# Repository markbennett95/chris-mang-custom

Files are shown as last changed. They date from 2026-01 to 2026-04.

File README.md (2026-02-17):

# Custom Dual OD - Chris Mang

Custom dual drive in a 1590BB featuring a Zendrive on one side, and a modified bluesbreaker on the other.

## v1.0.0-build
1590BB encl. Works with `1590BB-2` of the [Dual Effect Order Switching Board](https://github.com/markbennett95/dual-effect-order-switching-board). Zendrive schematic is unchanged, using the "version" switch and a DG412. The Bluesbreaker is a pretty straight up clone with added clean blend.

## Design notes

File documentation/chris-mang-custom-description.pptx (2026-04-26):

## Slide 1

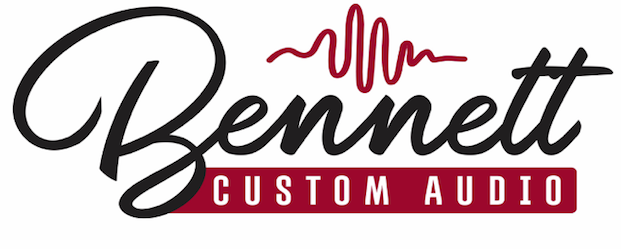
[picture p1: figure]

Custom Dual Overdrive

Introduction:
This custom-designed pedal features two independent overdrive circuits with order switching. The overdrives are modified versions of the Marshall BluesBreaker (“BB”), and the Zendrive by Hermida Audio (“Zendrive”). This pedal must be powered by a 9-18VDC, centre-negative power supply, capable of delivering 100mA of current – It does not have room for a battery inside. Like all our pedals, This pedal was designed and assembled by hand in St. John’s, NL.

Controls:
- BB VOL: Controls the output level of the BB. Turn it up for a louder signal.
- BB GAIN: Determines the amount of distortion in the BB. Turn it up for a more distorted, sustaining tone with more harmonics. Turn it down for a cleaner sound.
- BB CLEAN: A clean blend control that allows you to blend in some of the input signal in with the output signal of the overdrive. Counter-clockwise gives no clean signal, turning it up gives increasingly more clean signal in the output.
- BB PRESENCE: Enables fine-tuning of the overall brightness of the BB. We recommend turn it all the way counter-clockwise to start, then increase to taste if you find the tone to be too warm.
- BB TREBLE: Controls how warm or bright the BB output will be. Turn it down for a warmer tone, up for a brighter tone.
- ZEN VOL: Controls the output level of the Zendrive. Turn it up for a louder signal.
- ZEN GAIN: Determines the amount of distortion in the Zendrive. Turn it up for a more distorted, sustaining tone with more harmonics. Turn it down for a cleaner sound.
- ZEN TONE: Controls how warm or bright the tone will be. Turn it up for a bright sound.
- ZEN VERSION SWITCH: Sets the “version” of the Zendrive. Version I is brighter, with asymmetric clipping, less bass, and less overall gain. Version II has more gain, bass, and symmetric clipping for a warmer, fuzzier tone.
- ZEN VOICE: Sets the pre-gain bass of the Zendrive. Turning it down gives a warmer, less distorted sound. Turning it up gives a brighter sound with more overall gain.
- BB Footswitch: Toggles the BB on or off with true bypass. IF the LED next to it is illuminated, your signal is passing through the effect.
- Order Switch: Sets the order of the two overdrive circuits. UP puts the Zendrive before the BB in your signal chain, DOWN puts the BB before the Zendrive.
- ZEN Footswitch: Toggles the Zendrive on or off with true bypass. IF the LED next to it is illuminated, your signal is passing through the effect.

V1.0.0

www.bennettcustomaudio.ca
bennettcustomaudio@gmail.com

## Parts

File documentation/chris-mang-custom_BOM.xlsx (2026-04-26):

Value | Qty | Reference | Footprint
100nF | 3 | C14,C32,C33 | Capacitor_SMD:C_0805_2012Metric_Pad1.18x1.45mm_HandSolder
1uF | 1 | C11 | Capacitor_SMD:C_0805_2012Metric_Pad1.18x1.45mm_HandSolder
FerriteBead_Small | 3 | FB1,FB2,FB3 | Inductor_SMD:L_0805_2012Metric_Pad1.15x1.40mm_HandSolder
10k | 5 | R1,R17,R18,R42,R43 | Resistor_SMD:R_0805_2012Metric_Pad1.20x1.40mm_HandSolder
10M | 1 | R6 | Resistor_SMD:R_0805_2012Metric_Pad1.20x1.40mm_HandSolder
9V1 Zener | 1 | D1 | Diode_SMD:D_SOD-323_HandSoldering
Q_PMOS_GSD | 1 | Q1 | Package_TO_SOT_SMD:SOT-23_Handsoldering
BC848C | 2 | Q5,Q6 | Package_TO_SOT_SMD:SOT-23_Handsoldering
2N7002 | 3 | Q2,Q3,Q4 | Package_TO_SOT_SMD:SOT-23_Handsoldering
TLV9352 | 1 | U4 | Package_SO:SOIC-8_3.9x4.9mm_P1.27mm
NJM4580 | 1 | U3 | Package_SO:SOIC-8_3.9x4.9mm_P1.27mm
OPA1642 | 1 | U2 | Package_SO:SOIC-8_3.9x4.9mm_P1.27mm
DG412xY | 1 | U1 | Package_SO:SOIC-16_3.9x9.9mm_P1.27mm
1k | 3 | R8,R14,R29 | bca-footprints:R_L3.6mm_D1.6mm_P5.00mm_Horizontal
6.8k | 2 | R27,R30 | bca-footprints:R_L3.6mm_D1.6mm_P5.00mm_Horizontal
10k | 9 | R7,R10,R11,R13,R20,R26,R33,R40,R41 | bca-footprints:R_L3.6mm_D1.6mm_P5.00mm_Horizontal
18k | 1 | R12 | bca-footprints:R_L3.6mm_D1.6mm_P5.00mm_Horizontal
22k | 2 | R2,R3 | bca-footprints:R_L3.6mm_D1.6mm_P5.00mm_Horizontal
27k | 1 | R21 | bca-footprints:R_L3.6mm_D1.6mm_P5.00mm_Horizontal
33k | 1 | R22 | bca-footprints:R_L3.6mm_D1.6mm_P5.00mm_Horizontal
39k | 1 | R24 | bca-footprints:R_L3.6mm_D1.6mm_P5.00mm_Horizontal
100k | 6 | R15,R16,R31,R34,R35,R37 | bca-footprints:R_L3.6mm_D1.6mm_P5.00mm_Horizontal
150k | 1 | R25 | bca-footprints:R_L3.6mm_D1.6mm_P5.00mm_Horizontal
180k | 1 | R36 | bca-footprints:R_L3.6mm_D1.6mm_P5.00mm_Horizontal
220k | 1 | R28 | bca-footprints:R_L3.6mm_D1.6mm_P5.00mm_Horizontal
470k | 1 | R5 | bca-footprints:R_L3.6mm_D1.6mm_P5.00mm_Horizontal
680k | 1 | R9 | bca-footprints:R_L3.6mm_D1.6mm_P5.00mm_Horizontal
1M | 4 | R19,R23,R32,R39 | bca-footprints:R_L3.6mm_D1.6mm_P5.00mm_Horizontal
2.2M | 1 | R4 | bca-footprints:R_L3.6mm_D1.6mm_P5.00mm_Horizontal
1N4148 | 6 | D5,D6,D7,D8,D9,D10 | bca-footprints:Diode_DO-35_P5.00mm
1N5711 | 4 | D2,D3,D4,D11 | bca-footprints:Diode_DO-35_P5.00mm
47pF | 1 | C26 | bca-footprints:C_Ceramic_L4.0mm_W2.5mm_P2.50mm
100pF | 3 | C6,C18,C34 | bca-footprints:C_Ceramic_L4.0mm_W2.5mm_P2.50mm
470pF | 1 | C9 | bca-footprints:C_Ceramic_L4.0mm_W2.5mm_P2.50mm
3.3nF | 1 | C7 | bca-footprints:C_Film_L7.2mm_W2.5mm_P5.00mm
10nF | 6 | C15,C16,C17,C20,C21,C28 | bca-footprints:C_Film_L7.2mm_W2.5mm_P5.00mm
47nF | 1 | C25 | bca-footprints:C_Film_L7.2mm_W2.5mm_P5.00mm
0.1uF | 1 | C19 | bca-footprints:C_Film_L7.2mm_W2.5mm_P5.00mm
0.22uF | 3 | C4,C5,C8 | bca-footprints:C_Film_L7.2mm_W3.5mm_P5.00mm
0.47uF | 2 | C3,C10 | bca-footprints:C_Film_L7.2mm_W3.5mm_P5.00mm
1uF | 1 | C22 | bca-footprints:C_Film_L7.2mm_W5.00mm_P5.00mm
1uF | 1 | C23 | bca-footprints:CP_Radial_D4.0mm_P1.50mm
10uF | 3 | C24,C27,C29 | bca-footprints:CP_Radial_D4.0mm_P1.50mm
100uF | 6 | C1,C2,C12,C13,C30,C31 | bca-footprints:CP_Radial_D6.3mm_P2.50mm
SW_DIP_SPDT_2pos | 1 | SW2 | bca-footprints:DIP-8_W7.62mm_Socket
AudioJack_TRS | 2 | J2,J3 | bca-footprints:Rean_NYS215
Barrel_Jack_Switch | 1 | J1 | bca-footprints:DC_Jack_DC005
GNDSpring | 1 | G1 | bca-footprints:Keystone_628
10kC | 1 | RV1 | bca-footprints:R_POT
25kB | 1 | RV6 | bca-footprints:R_POT
50kB | 1 | RV3 | bca-footprints:R_POT
100kA | 3 | RV4,RV8,RV9 | bca-footprints:R_POT
100kB | 1 | RV5 | bca-footprints:R_POT
1MA | 1 | RV2 | bca-footprints:R_POT
SW_SPDT | 1 | SW1 | bca-footprints:SW_Toggle_SPDT_SolderLug
100kA | 1 | RV7 | bca-footprints:R_POT_9mm

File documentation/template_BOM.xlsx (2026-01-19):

Weather Man v2.1.2 BOM - Nov 2021
Designation | Quantity | Designator
MMBFJ201 | 4 | Q1,Q2,Q3,Q4
47R | 1 | R30
1k | 5 | R4,R7,R20,R22,R25
2.7k | 2 | R6,R27
4.7k | 1 | R19
6.8k | 3 | R17,R29,R33
10k | 2 | R16,R21
12k | 1 | R9
33k | 2 | R11,R15
39k | 1 | R13
68k | 2 | R2,R34
100k | 2 | R31,R32
220k | 1 | R18
470k | 1 | R12
1M | 7 | R1,R3,R5,R10,R14,R24,R26
1N914 | 4 | D3,D1,D2,D4
1N4001 | 1 | D5
100pF | 3 | C1,C10,C12
100nF | 1 | C23
NJM4580 | 1 | U1
1nF | 2 | C3,C7
4.7nF | 1 | C16
6.8nF | 3 | C2,C21
10nF | 4 | C9,C8,C14,C20
47nF | 2 | C13,C17
0.1uF | 5 | C4,C5,C11,C15,C19
100uF | 2 | C22,C24
25kB | 2 | RV1,RV4
100kA | 1 | RV2
100kB | 2 | RV3,RV5
50kB | 1 | RV6
SW_SPDT_DIP | 1 | SW1
SW_SPDT | 1 | SW2

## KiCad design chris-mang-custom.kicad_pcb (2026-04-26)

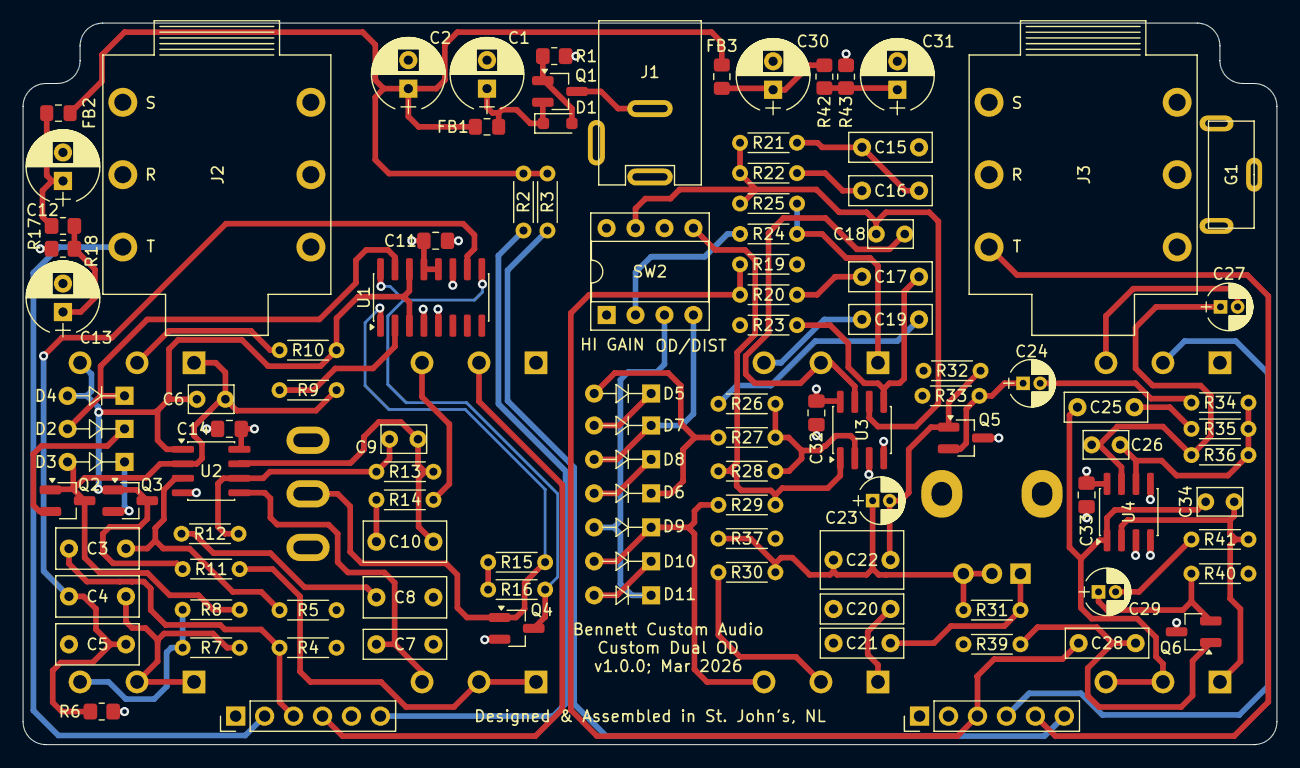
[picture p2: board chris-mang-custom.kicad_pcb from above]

Board: 4 copper layers, 110.0 x 63.3 mm, 117 parts (1 on the bottom side), 72 nets.

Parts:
C1, C2: 100uF; CP_Radial_D6.3mm_P2.50mm
C3: 0.47u; C_Film_L7.2mm_W3.5mm_P5.00mm
C4, C5: 0.22u; C_Film_L7.2mm_W3.5mm_P5.00mm
C6, C18, C34: 100p; C_Ceramic_L4.0mm_W2.5mm_P2.50mm
C7: 3.3nF; C_Film_L7.2mm_W2.5mm_P5.00mm
C8: 0.22uF; C_Film_L7.2mm_W3.5mm_P5.00mm
C9: 470p; C_Ceramic_L4.0mm_W2.5mm_P2.50mm
C10: 0.47uF; C_Film_L7.2mm_W3.5mm_P5.00mm
C11: 1u; C_0805_2012Metric_Pad1.18x1.45mm_HandSolder
C12, C13, C30, C31: 100u; CP_Radial_D6.3mm_P2.50mm
C14, C32, C33: 100n; C_0805_2012Metric_Pad1.18x1.45mm_HandSolder
C15, C16, C17, C20, C21, C28: 10n; C_Film_L7.2mm_W2.5mm_P5.00mm
C19: 0.1u; C_Film_L7.2mm_W2.5mm_P5.00mm
C22: 1u; C_Film_L7.2mm_W5.00mm_P5.00mm
C23: 1u; CP_Radial_D4.0mm_P1.50mm
C24, C27, C29: 10u; CP_Radial_D4.0mm_P1.50mm
C25: 47n; C_Film_L7.2mm_W2.5mm_P5.00mm
C26: 47p; C_Ceramic_L4.0mm_W2.5mm_P2.50mm
D1: 9V1 Zener; D_SOD-323_HandSoldering
D2, D3, D4, D11: 1N5711; Diode_DO-35_P5.00mm
D5, D6, D7, D8, D9, D10: 1N4148; Diode_DO-35_P5.00mm
FB1, FB2, FB3: FerriteBead_Small; L_0805_2012Metric_Pad1.15x1.40mm_HandSolder
G1: GNDSpring; Keystone_628
J1: Barrel_Jack_Switch; DC_Jack_DC005
J2, J3: AudioJack_TRS; Rean_NYS215
J4, J5: Conn_01x06; Pin_Header_Straight_1x06_Pitch2.54mm
Q1: Q_PMOS_GSD; SOT-23_Handsoldering
Q2, Q3, Q4: 2N7002; SOT-23_Handsoldering
Q5, Q6: BC848C; SOT-23_Handsoldering
R1, R17, R18, R42, R43: 10k; R_0805_2012Metric_Pad1.20x1.40mm_HandSolder
R2, R3: 22k; R_L3.6mm_D1.6mm_P5.00mm_Horizontal
R4: 2.2M; R_L3.6mm_D1.6mm_P5.00mm_Horizontal
R5: 470k; R_L3.6mm_D1.6mm_P5.00mm_Horizontal
R6: 10M; R_0805_2012Metric_Pad1.20x1.40mm_HandSolder
R7, R10, R11, R13, R20, R26, R33, R40, R41: 10k; R_L3.6mm_D1.6mm_P5.00mm_Horizontal
R8, R14, R29: 1k; R_L3.6mm_D1.6mm_P5.00mm_Horizontal
R9: 680k; R_L3.6mm_D1.6mm_P5.00mm_Horizontal
R12: 18k; R_L3.6mm_D1.6mm_P5.00mm_Horizontal
R15, R16, R31, R34, R35, R37: 100k; R_L3.6mm_D1.6mm_P5.00mm_Horizontal
R19, R23, R32, R39: 1M; R_L3.6mm_D1.6mm_P5.00mm_Horizontal
R21: 27k; R_L3.6mm_D1.6mm_P5.00mm_Horizontal
R22: 33k; R_L3.6mm_D1.6mm_P5.00mm_Horizontal
R24: 39k; R_L3.6mm_D1.6mm_P5.00mm_Horizontal
R25: 150k; R_L3.6mm_D1.6mm_P5.00mm_Horizontal
R27, R30: 6.8k; R_L3.6mm_D1.6mm_P5.00mm_Horizontal
R28: 220k; R_L3.6mm_D1.6mm_P5.00mm_Horizontal
R36: 180k; R_L3.6mm_D1.6mm_P5.00mm_Horizontal
RV1: 10kC; R_POT
RV2: 1MA; R_POT
RV3: 50kB; R_POT
RV4, RV8, RV9: 100kA; R_POT
RV5: 100kB; R_POT
RV6: 25kB; R_POT
RV7: 100kA; R_POT_9mm
SW1: SW_SPDT; SW_Toggle_SPDT_SolderLug
SW2: SW_DIP_SPDT_2pos; DIP-8_W7.62mm_Socket
U1: DG412xY; SOIC-16_3.9x9.9mm_P1.27mm
U2: OPA2134; SOIC-8_3.9x4.9mm_P1.27mm
U3: NJM4580; SOIC-8_3.9x4.9mm_P1.27mm
U4: TLV9352; SOIC-8_3.9x4.9mm_P1.27mm

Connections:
+9V: C2.1, FB1.2, FB2.1, FB3.1, R2.2, R3.2
/V+0: J4.6, R2.1
/V+1: J5.6, R3.1
/Zendrive/4.5V: C13.1, R5.1, R17.1, R18.2
/Zendrive/9V: C11.1, C12.1, C14.1, FB2.2, R15.2, R16.2, R17.2, U1.12 (VL), U1.13 (V+), U2.8 (V+)
/Zendrive/Q1D: Q4.3 (D), R16.1, U1.9, U1.16
/Zendrive/Q1G: Q4.1 (G), R15.1, SW1.2 (B), U1.1
/bluesbreaker-return: J5.4, RV8.2
/bluesbreaker-send: C28.1, J5.3, R19.2, R20.1
/bluesbreaker/4.5V: C20.1, C21.1, C31.1, R23.1, R32.1, R37.1, R39.1, R42.1, R43.2, SW2.6 (A), U3.3 (+), U4.3 (+), U4.5 (+)
/bluesbreaker/9V: C30.1, C32.1, C33.1, FB3.2, Q5.3 (C), Q6.3 (C), R42.2, U3.8 (V+), U4.8 (V+)
/bluesbreaker/sw2: R24.1, SW2.2 (D)
/bluesbreaker/sw3: D9.2 (A), D11.1 (K), SW2.3 (C)
/bluesbreaker/sw4: D7.1 (K), D8.2 (A), SW2.4 (D)
/bluesbreaker/sw5: R28.2, R29.1, SW2.5 (B), U3.1
/bluesbreaker/sw7: C18.1, R21.2, R22.2, R25.1, SW2.7 (B), U3.6 (-)
/input_jack: J2.1 (T), J4.2
/output_jack: J3.1 (T), J5.5
/zendrive_return: J4.4, RV4.2
/zendrive_send: C3.1, J4.3, R4.2
Earth: C1.2, C2.2, C5.1, C7.2, C8.1, C11.2, C12.2, C13.2, C14.2, C15.1, C30.2, C31.2, C32.2, C33.2, G1.1, J1.1, J2.2 (R), J2.3 (S), J2.4 (TS), J2.5 (RS), J2.6 (SS), J3.2 (R), J3.3 (S), J3.4 (TS), J3.5 (RS), J3.6 (SS), J4.1, J5.1, Q4.2 (S), R1.1, R4.1, R6.1, R18.1, R19.1, R33.1, R40.1, R43.1, RV4.1, RV8.1, SW1.1 (A), U1.4 (V-), U1.5 (GND), U1.11, U2.4 (V-), U3.4 (V-), U4.4 (V-)
unnamed: C4.1, C5.2, R6.2, U1.10
unnamed: C4.2, R7.1, RV1.1, RV1.2
unnamed: C8.2, R12.1
unnamed: C9.2, C10.1, R13.2, U2.7
unnamed: C10.2, R14.1
unnamed: C15.2, C16.1, R21.1
unnamed: C16.2, R22.1
unnamed: C17.1, R20.2
unnamed: C18.2, RV5.2, U3.7
unnamed: C19.1, RV5.3
unnamed: C19.2, R26.1
unnamed: C20.2, RV6.1
unnamed: C21.2, R31.1, RV7.1
unnamed: C22.1, C23.1, R30.2, R31.2, R37.2, RV7.2, RV7.3
unnamed: C24.2, R34.1
unnamed: C25.1, C34.2, RV9.2, RV9.3, U4.1
unnamed: C25.2, R35.1
unnamed: C26.2, C27.1, R36.2, U4.7
unnamed: C27.2, RV8.3
unnamed: C29.2, R41.1
unnamed: D1.2 (A), Q1.1 (G), R1.2
unnamed: C1.1, D1.1 (K), FB1.1, Q1.2 (S)
unnamed: D2.2 (A), D4.1 (K), U1.15
unnamed: D2.1 (K), Q2.2 (S)
unnamed: C6.1, D3.2 (A), Q2.1 (G), Q2.3 (D), R8.2, R9.1, RV2.1, U2.2 (-)
unnamed: D3.1 (K), Q3.2 (S)
unnamed: C6.2, D4.2 (A), Q3.1 (G), Q3.3 (D), R10.2, R11.1, RV2.3, U1.3, U1.14, U2.1
unnamed: D5.2 (A), D6.1 (K), R27.2
unnamed: D5.1 (K), D7.2 (A)
unnamed: D6.2 (A), D8.1 (K)
unnamed: D9.1 (K), D10.2 (A), R29.2, RV6.3
unnamed: D10.1 (K), D11.2 (A)
unnamed: J1.2, Q1.3 (D)
unnamed: C22.2, C23.2, Q5.1 (B), R32.2
unnamed: C24.1, Q5.2 (E), R33.2
unnamed: C28.2, Q6.1 (B), R39.2
unnamed: C29.1, Q6.2 (E), R40.2
unnamed: R7.2, R8.1, RV1.3
unnamed: R9.2, U1.2
unnamed: R10.1, RV2.2
unnamed: R11.2, RV3.1, RV3.2
unnamed: R14.2, RV4.3
unnamed: R24.2, R25.2, RV5.1
unnamed: R30.1, RV6.2
unnamed: C3.2, R5.2, U2.3 (+)
unnamed: C7.1, RV3.3, U2.5 (+)
unnamed: C9.1, R12.2, R13.1, U2.6 (-)
unnamed: R26.2, R27.1, R28.1, U3.2 (-)
unnamed: C17.2, R23.2, U3.5 (+)
unnamed: C34.1, R41.2, RV9.1, U4.2 (-)
unnamed: C26.1, R34.2, R35.2, R36.1, U4.6 (-)

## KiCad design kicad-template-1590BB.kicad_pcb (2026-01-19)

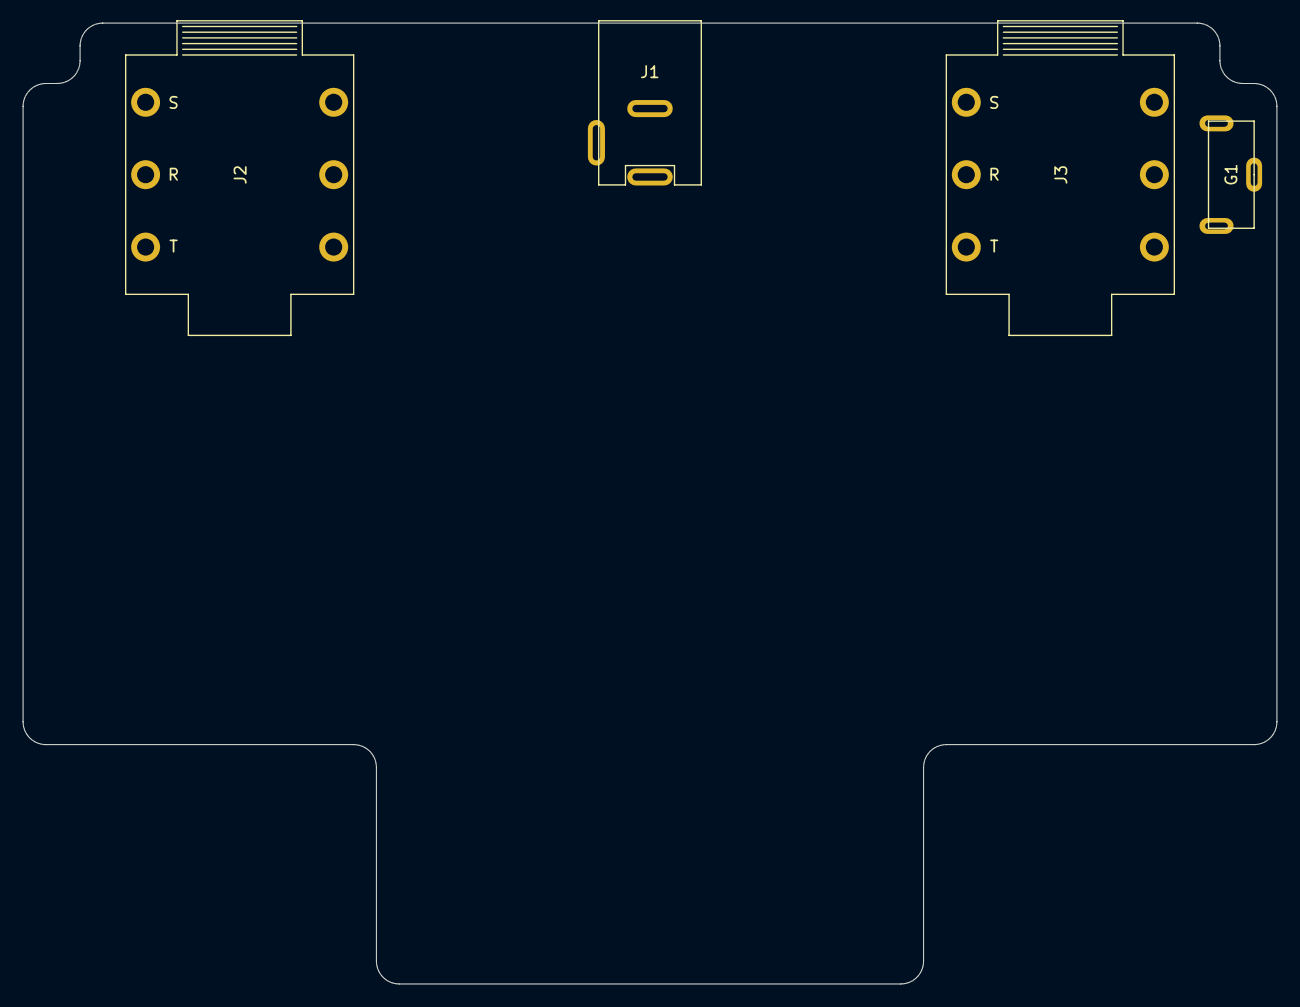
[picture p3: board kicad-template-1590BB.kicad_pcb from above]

Board: 2 copper layers, 110.0 x 84.3 mm, 4 parts (0 on the bottom side), 2 nets, no tracks yet.

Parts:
G1: GNDSpring; Keystone_628
J1: Barrel_Jack_Switch; DC_Jack_DC005
J2, J3: AudioJack_TRS; Rean_NYS215

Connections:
Earth: G1.1, J2.3, J2.4, J2.6, J3.2, J3.3, J3.4, J3.5, J3.6
unnamed: J1.1, J2.2

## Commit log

2026-02-13 finished bd2 schematic
    [blues-driver.kicad_sch, riley-penny-custom.kicad_sch, zendrive.kicad_sch]
2026-02-17 added bluesbreaker schematic
    [blues-driver.kicad_sch, bluesbreaker.kicad_sch, chris-mang-custom.kicad_sch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]
2026-02-18 first route of PCB
    [bluesbreaker.kicad_sch, chris-mang-custom.kicad_pcb, chris-mang-custom.kicad_sch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]
2026-02-26 finalized schematic
    [bluesbreaker.kicad_sch, chris-mang-custom.kicad_pcb, chris-mang-custom.kicad_sch]
2026-03-05 first draft PCB
    [bluesbreaker.kicad_sch, chris-mang-custom.kicad_pcb, zendrive.kicad_sch]
2026-03-13 generated gerbers
    [bluesbreaker.kicad_sch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]
2026-04-26 re-generated gerbers, finalized BOM
    [bluesbreaker.kicad_sch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]
